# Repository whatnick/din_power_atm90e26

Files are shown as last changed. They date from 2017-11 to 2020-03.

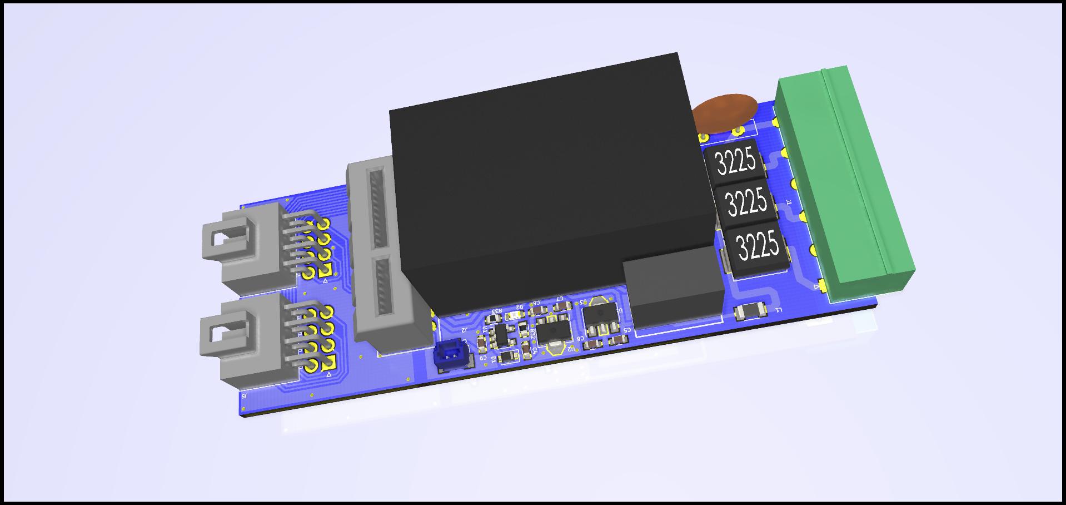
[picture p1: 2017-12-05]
din_power_atm90e26_front.jpg

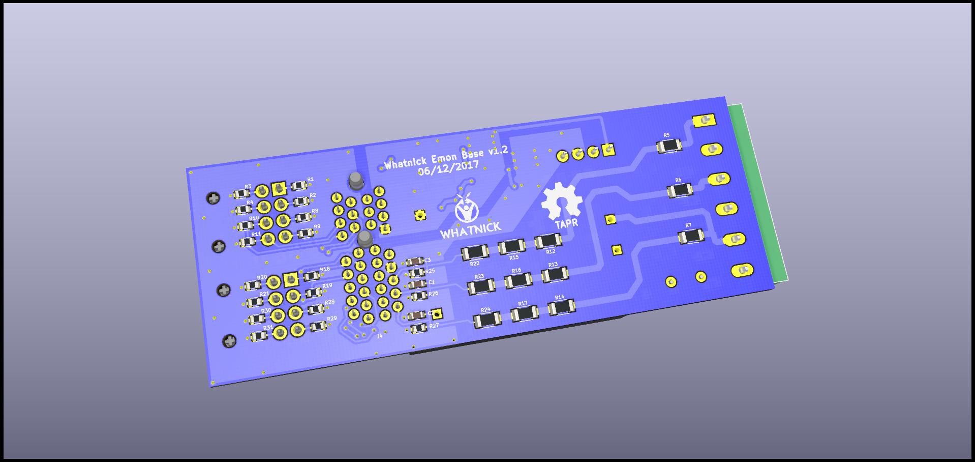
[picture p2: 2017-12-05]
din_power_atm90e26.jpg

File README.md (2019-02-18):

# DIN Rail Format Energy Meter Base Board
## Power SMPS module
- 90v-240v AC input
- Isolated 5V output
- 600mA / 3W power rating

## Over-voltage protection/over-current protection
- 0.1A rated PTC fuse
- 300V rated TVS suppressors, x1 per-phase

## Isolation
- 5v DC-DC isolator to power metering module

## Power supply clean-up
- x2 1117 series LDO for generating 3.3v from 5V input to clean up SMPS noise

## Backup-power
- MCP73831 series floating Lipo battery charger for backup lipo battery

## AC Voltage Sampler
- x3 Voltage divider ladders with 880K + 1K total serial resistance

## AC current Sampler
- x8 2.4ohm current sense resistor based CT clamp inputs

## Connectors
- 5.08mm spacing phoenix contact AC voltage connector
- Molex nanofit 2x4 type dense AC current clamp connectors

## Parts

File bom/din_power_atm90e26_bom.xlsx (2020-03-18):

References | manf# | Value | Footprint | Quantity
C4, C5, C6, C7, C8, C9 | 0603ZD105KAT2A | 1uF | C_0603 | 6
C1, C2, C3 | CC0603KRX7R9BB333 | 33n | C_0603 | 3
R5, R6, R7, R12, R13, R14, R15, R16, R17, R22, R23, R24 | CRCW1206220KFKEA | 220K | R_1206 | 12
R25, R26, R27, R33 | CRG0603F1K0 | 1K | R_0603 | 4
R1, R2, R3, R4, R8, R9, R10, R11, R18, R19, R20, R21, R28, R29, R30, R31 | CRL0603-FW-2R40ELF | 5.8R | R_0603 | 16
R32 | RT0603DRE072KL | 2K | R_0603 | 1
L1 | AIML-1206-R27K-T | Ferrite_Bead_Small | L_1206 | 1
D2 | LTST-C190KRKT | LED | LED_0603 | 1
D1 | PMEG1020EA | D_Schottky | D_SOD-323F | 1
U2, U3 | AP7365-33YG-13 | AP7365-33YG-13 | SOT-89-3 | 2
U4 | HLK-PM01 | Hi-Link_SMPS | HKLPM01 | 1
U1 | MCP73831T-3ACI/OT | MCP73831-2-OT | SOT-23-5 | 1
U5 | ROE-0505S | dc-dc | SIP4 | 1
F1 | 0ZRE0012FF1C | Polyfuse | C_Disc_D10.0mm_W2.5mm_P5.00mm | 1
RV1, RV2, RV3 | VP3225K401R275 | Varistor | SMD-4032 | 3
J4 | 10018784-10210TLF | CONN_02X18 | PCIE-36-SKT | 1
J3, J5 | 1053141108 | CONN_01X08 | Molex_NanoFit_2x04x2.50mm_Angled | 2
J1 | 1759059 | CONN_01X06 | PhoenixContact_MC-G_06x5.08mm_Angled | 1
J2 | BM02B-SRSS-TB(LFSN) | VBAT | JST_SH_BM02B-SRSS-TB_02x1.00mm_Straight | 1

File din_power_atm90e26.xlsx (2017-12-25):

Proj: | None |  |  |  |  |  | Board Qty: | 100
Co.: | None |  |  |  |  |  | Total Cost: | $0.00 |  |  |  | $0.00 |  |  |  |  | $0.00 |  |  |  |  | $0.00 |  |  |  |  | $0.00 |  |  |  |  | $0.00 |  |  |  |  | $0.00 |  |  |  |  | $0.00
Prj date: | None |  |  |  |  |  | Unit Cost: | $0.00 |  |  |  | 0 |  |  |  |  | 0 |  |  |  |  | 0 |  |  |  |  | 0 |  |  |  |  | 0 |  |  |  |  | 0 |  |  |  |  | 0
$ date: | 2017-12-25 13:13:31
Global Part Info |  |  |  |  |  |  |  |  | Digi-Key |  |  |  |  | Farnell |  |  |  |  | Mouser |  |  |  |  | Newark |  |  |  |  | Rs Components |  |  |  |  | Tme |  |  |  |  | Local
Refs | Value | Desc | Footprint | Manf | Manf# | Qty | Unit$ | Ext$ | Avail | Purch | Unit$ | Ext$ | Cat# | Avail | Purch | Unit$ | Ext$ | Cat# | Avail | Purch | Unit$ | Ext$ | Cat# | Avail | Purch | Unit$ | Ext$ | Cat# | Avail | Purch | Unit$ | Ext$ | Cat# | Avail | Purch | Unit$ | Ext$ | Cat# | Avail | Purch | Unit$ | Ext$ | Cat#
C1-C3 | 33n |  | Capacitors_SMD:C_0603 |  | CC0603KRX7R9BB333 | 0 | $0.00 | $0.00 | 132551 |  | $0.00 | $0.00 | 311-1429-1-ND (http://www.digikey.com/product-detail/en/yageo/CC0603KRX7R9BB333/311-1429-1-ND/2833735) |  |  |  |  |  |  |  |  |  |  | NonStk |  | $0.00 | $0.00 | 65R8273 (http://www.newark.com/webapp/wcs/stores/servlet/Search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) | 4 |  | $0.00 | $0.00 | 669-8836 (http://it.rs-online.com/web/c/?searchTerm=CC0603KRX7R9BB333+) | 33200 |  | $0.00 | $0.00 | CC0603KRX7R9333 (https://www.tme.eu/en/details/cc0603krx7r9333/0603-mlcc-smd-capacitors/yageo/cc0603krx7r9bb333/)
C4-C9 | 1uF |  | Capacitors_SMD:C_0603 |  | 0603ZD105KAT2A | 0 | $0.00 | $0.00 | 170608 |  | $0.00 | $0.00 | 478-1251-1-ND (http://www.digikey.com/product-detail/en/avx-corporation/0603ZD105KAT2A/478-1251-1-ND/564283) | 7506 |  | $0.00 | $0.00 | 1327684 (http://it.farnell.com/avx/0603zd105kat2a/condensatore-mlcc-x5r-1uf-10v/dp/1327684) |  |  |  |  |  | 19442 |  | $0.00 | $0.00 | 84K8388 (http://www.newark.com/avx/0603zd105kat2a/ceramic-capacitor-1uf-10v-x5r/dp/84K8388) |  |  |  |  |  | 10800 |  | $0.00 | $0.00 | 0603ZD105KAT2A (https://www.tme.eu/en/details/0603zd105kat2a/0603-mlcc-smd-capacitors/avx/)
D1 | D_Schottky |  | Diodes_SMD:D_SOD-323F |  | PMEG1020EA | 0 | $0.00 | $0.00 | NonStk |  | $0.00 | $0.00 | 1727-5185-1-ND (http://www.digikey.com/product-detail/en/nexperia-usa-inc/PMEG1020EA115/1727-5185-1-ND/2531784) | NonStk |  | $0.00 | $0.00 | 8737819 (http://it.farnell.com/nexperia/pmeg1020ea/diodo-schottky-sod-323/dp/8737819) |  |  |  |  |  | NonStk |  | $0.00 | $0.00 | 38K6864 (http://www.newark.com/nexperia/pmeg1020ea/schottky-rectifier-2a-10v-sc-76/dp/38K6864) | 1420 |  | $0.00 | $0.00 | 485-470 (http://it.rs-online.com/web/c/?searchTerm=PMEG1020EA+)
D2 | LED |  | LEDs:LED_0603 |  | LTST-C190KRKT | 0 | $0.00 | $0.00 | 1033408 |  | $0.00 | $0.00 | 160-1436-1-ND (http://www.digikey.com/product-detail/en/lite-on-inc/LTST-C190KRKT/160-1436-1-ND/386816) |  |  |  |  |  |  |  |  |  |  | 1991 |  | $0.00 | $0.00 | 09J9435 (http://www.newark.com/lumex/sml-lx0603siw-tr/led-red-0-8mm-x-1mm-60mcd-636nm/dp/09J9435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) | 100 |  | $0.00 | $0.00 | 692-0981 (http://it.rs-online.com/web/c/?searchTerm=LTST-C190KRKT+) | NonStk |  | $0.00 | $0.00 | LTST-C190KRKT (https://www.tme.eu/en/details/ltst-c190krkt/smd-colour-leds/liteon/)
F1 | Polyfuse |  | Capacitors_THT:C_Disc_D10.0mm_W2.5mm_P5.00mm |  | 0ZRE0012FF1C | 0 | $0.00 | $0.00 | 16473 |  | $0.00 | $0.00 | 507-1350-ND (http://www.digikey.com/scripts/DkSearch/dksus.dll?WT.z_header=search_go&lang=en)
J1 | CONN_01X06 |  | Connectors_Phoenix:PhoenixContact_MC-G_06x5.08mm_Angled |  | 1759059 | 0 | $0.00 | $0.00 | 775 |  | $0.00 | $0.00 | 277-1099-ND (http://www.digikey.com/scripts/DkSearch/dksus.dll?WT.z_header=search_go&lang=en&keywords=1759059+) | 43530 |  | $0.00 | $0.00 | 1759059 (http://it.farnell.com/multicomp/mc0603n330j500ct/condens-mlcc-c0g-np0-33pf-50v/dp/1759059) |  |  |  |  |  | NonStk |  |  |  | 14X6549 (http://www.newark.com/phoenix-contact/1759059/mstb-2-5-6-g-5-08/dp/14X6549)
J2 | VBAT |  | Connectors_JST:JST_SH_BM02B-SRSS-TB_02x1.00mm_Straight |  | BM02B-SRSS-TB(LFSN) | 0 | $0.00 | $0.00 | 24764 |  | $0.00 | $0.00 | 455-1788-1-ND (http://www.digikey.com/product-detail/en/jst-sales-america-inc/BM02B-SRSS-TB-LF-SN/455-1788-1-ND/926859) | 31065 |  | $0.00 | $0.00 | 1679127 (http://it.farnell.com/webapp/wcs/stores/servlet/Search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) |  |  |  |  |  | 5974 |  | $0.00 | $0.00 | 26P0950 (http://www.newark.com/webapp/wcs/stores/servlet/Search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)
J3,J5 | CONN_01X08 |  | Connectors_Molex:Molex_NanoFit_2x04x2.50mm_Angled |  | 1053141108 | 0 | $0.00 | $0.00 | 1652 |  | $0.00 | $0.00 | WM16909-ND (http://www.digikey.com/scripts/DkSearch/dksus.dll?WT.z_header=search_go&lang=en&keywords=1053141108+) | 131 |  | $0.00 | $0.00 | 2820690 (http://it.farnell.com/molex/105314-1108/connettore-bas-8pos-r-a-2file2/dp/2820690) |  |  |  |  |  | 1716 |  | $0.00 | $0.00 | 33AC7688 (http://www.newark.com/webapp/wcs/stores/servlet/Search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)
J4 | CONN_02X18 |  | hi-link_smps:PCIE-36-SKT |  | 10018784-10210TLF | 0 | $0.00 | $0.00 | 2100 |  | $0.00 | $0.00 | 609-2029-ND (http://www.digikey.com/scripts/DkSearch/dksus.dll?WT.z_header=search_go&lang=en)
L1 | Ferrite_Bead_Small |  | Inductors_SMD:L_1206 |  | AIML-1206-R27K-T | 0 | $0.00 | $0.00 | 29927 |  | $0.00 | $0.00 | 535-11684-1-ND (http://www.digikey.com/product-detail/en/abracon-llc/AIML-1206-R27K-T/535-11684-1-ND/2782899)
R1-R4,R8-R11,R18-R21,R28-R31 | 5.8R |  | Resistors_SMD:R_0603 |  | CPF0603B5R76E1 | 0 | $0.00 | $0.00 | NonStk |  | $0.00 | $0.00 | CPF0603B5R76E1-ND (http://www.digikey.com/scripts/DkSearch/dksus.dll?WT.z_header=search_go&lang=en) | 93 |  | $0.00 | $0.00 | 2331306 (http://it.farnell.com/te-connectivity/cpf0603b5r76e1/res-film-sott-5r76-0-1-0-063w/dp/2331306) |  |  |  |  |  | 1000 |  | $0.00 | $0.00 | 06AC1362 (http://www.newark.com/te-connectivity/cpf0603b5r76e1/res-thin-film-5r76-0-1-0-063w/dp/06AC1362)
R25-R27,R33 | 1K |  | Resistors_SMD:R_0603 |  | CRG0603F1K0 | 0 | $0.00 | $0.00 | 217123 |  | $0.00 | $0.00 | A106049CT-ND (http://www.digikey.com/product-detail/en/te-connectivity-passive-product/CRG0603F1K0/A106049CT-ND/3477689) |  |  |  |  |  |  |  |  |  |  | NonStk |  | $0.00 | $0.00 | 20R1193 (http://www.newark.com/te-connectivity-neohm/crg0603f1k0-10/crg0603-1-1k0-10k-rl/dp/20R1193)
R32 | 2K |  | Resistors_SMD:R_0603 |  | RT0603DRE072KL | 0 | $0.00 | $0.00 | 10769 |  | $0.00 | $0.00 | 311-2525-1-ND (http://www.digikey.com/product-detail/en/yageo/RT0603DRE072KL/311-2525-1-ND/6128944)
R5-R7,R12-R17,R22-R24 | 220K |  | Resistors_SMD:R_1206 |  | CRCW1206220KFKEA | 0 | $0.00 | $0.00 | 29958 |  | $0.00 | $0.00 | 541-220KFCT-ND (http://www.digikey.com/product-detail/en/vishay-dale/CRCW1206220KFKEA/541-220KFCT-ND/1182024) | 16072 |  | $0.00 | $0.00 | 2139620 (http://it.farnell.com/vishay/crcw1206220kfkea/res-film-spesso-220k-1-0-25w-1206/dp/2139620) |  |  |  |  |  | 6046 |  | $0.00 | $0.00 | 53K2157 (http://www.newark.com/vishay/crcw1206220kfkea/res-thick-film-220k-1-0-25w-1206/dp/53K2157) |  |  |  |  |  | NonStk |  | $0.00 | $0.00 | CRCW1206220KFKEA (https://www.tme.eu/en/details/crcw1206220kfkea/1206-smd-resistors/vishay/)
RV1-RV3 | Varistor |  | SMD_Packages:SMD-4032 |  | VP3225K401R275 | 0 | $0.00 | $0.00 | 2631 |  | $0.00 | $0.00 | 399-13808-1-ND (http://www.digikey.com/product-detail/en/kemet/VP3225K401R275/399-13808-1-ND/6362952) | 6035 |  | $0.00 | $0.00 | 2717784 (http://it.farnell.com/kemet/vp3225k401r275/varistore-mlv-710v-3225/dp/2717784) |  |  |  |  |  | 6035 |  | $0.00 | $0.00 | 14AC5483 (http://www.newark.com/webapp/wcs/stores/servlet/Search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)
U1 | MCP73831-2-OT |  | TO_SOT_Packages_SMD:SOT-23-5 |  | MCP73831T-3ACI/OT | 0 | $0.00 | $0.00 | NonStk |  | $0.00 | $0.00 | MCP73831T-3ACI/OTTR-ND (http://www.digikey.com/product-detail/en/microchip-technology/MCP73831T-3ACI-OT/MCP73831T-3ACI-OTTR-ND/964307) |  |  |  |  |  |  |  |  |  |  | NonStk |  | $0.00 | $0.00 | 56K7051 (http://www.newark.com/webapp/wcs/stores/servlet/Search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)
U2,U3 | AP7365-33YG-13 |  | TO_SOT_Packages_SMD:SOT-89-3 |  | AP7365-33YG-13 | 0 | $0.00 | $0.00 | NonStk |  | $0.00 | $0.00 | AP7365-33YG-13DI-ND (http://www.digikey.com/scripts/DkSearch/dksus.dll?WT.z_header=search_go&lang=en)
U4 | Hi-Link_SMPS |  | hi-link_smps:HKLPM01 |  |  | 0 | $0.00 | $0.00 |  |  |  |  |  |  |  |  |  |  |  |  |  |  |  |  |  |  |  |  |  |  |  |  |  |  |  |  |  |  | NonStk |  | $0.00 | $0.00 | #AB80C0DC401ACD3
U5 | dc-dc |  | hi-link_smps:SIP4 |  | ROE-0505S | 0 | $0.00 | $0.00 | 12646 |  | $0.00 | $0.00 | 945-1655-5-ND (http://www.digikey.com/scripts/DkSearch/dksus.dll?WT.z_header=search_go&lang=en&keywords=ROE-0505S+) | 7726 |  | $0.00 | $0.00 | 2218597 (http://it.farnell.com/webapp/wcs/stores/servlet/Search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) |  |  |  |  |  | 198 |  | $0.00 | $0.00 | 63X9545 (http://www.newark.com/webapp/wcs/stores/servlet/Search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) | 42 |  | $0.00 | $0.00 | 777-3285 (http://it.rs-online.com/web/c/?searchTerm=ROE-0505S+)
 |  |  |  |  |  |  |  |  |  | 0 |  |  |  |  | 0 |  |  |  |  | 0 |  |  |  |  | 0 |  |  |  |  | 0 |  |  |  |  | 0 |  |  |  |  | 0
 |  |  |  |  |  |  |  |  |  | 0 | 0 | 0 |  |  | 0 | 0 | 0 |  |  | 0 | 0 | 0 |  |  | 0 | 0 | 0 |  |  | 0 | 0 | 0 |  |  | 0 | 0 | 0 |  |  | 0 | 0 | 0
 |  |  |  |  |  |  |  |  |  | 0 | 0 | 0 |  |  | 0 | 0 | 0 |  |  | 0 | 0 | 0 |  |  | 0 | 0 | 0 |  |  | 0 | 0 | 0 |  |  | 0 | 0 | 0 |  |  | 0 | 0 | 0
 |  |  |  |  |  |  |  |  |  | 0 | 0 | 0 |  |  | 0 | 0 | 0 |  |  | 0 | 0 | 0 |  |  | 0 | 0 | 0 |  |  | 0 | 0 | 0 |  |  | 0 | 0 | 0 |  |  | 0 | 0 | 0
 |  |  |  |  |  |  |  |  |  | 0 | 0 | 0 |  |  | 0 | 0 | 0 |  |  | 0 | 0 | 0 |  |  | 0 | 0 | 0 |  |  | 0 | 0 | 0 |  |  | 0 | 0 | 0 |  |  | 0 | 0 | 0
 |  |  |  |  |  |  |  |  |  | 0 | 0 | 0 |  |  | 0 | 0 | 0 |  |  | 0 | 0 | 0 |  |  | 0 | 0 | 0 |  |  | 0 | 0 | 0 |  |  | 0 | 0 | 0 |  |  | 0 | 0 | 0
 |  |  |  |  |  |  |  |  |  | 0 | 0 | 0 |  |  | 0 | 0 | 0 |  |  | 0 | 0 | 0 |  |  | 0 | 0 | 0 |  |  | 0 | 0 | 0 |  |  | 0 | 0 | 0 |  |  | 0 | 0 | 0
 |  |  |  |  |  |  |  |  |  | 0 | 0 | 0 |  |  | 0 | 0 | 0 |  |  | 0 | 0 | 0 |  |  | 0 | 0 | 0 |  |  | 0 | 0 | 0 |  |  | 0 | 0 | 0 |  |  | 0 | 0 | 0
 |  |  |  |  |  |  |  |  |  | 0 | 0 | 0 |  |  | 0 | 0 | 0 |  |  | 0 | 0 | 0 |  |  | 0 | 0 | 0 |  |  | 0 | 0 | 0 |  |  | 0 | 0 | 0 |  |  | 0 | 0 | 0
 |  |  |  |  |  |  |  |  |  | 0 | 0 | 0 |  |  | 0 | 0 | 0 |  |  | 0 | 0 | 0 |  |  | 0 | 0 | 0 |  |  | 0 | 0 | 0 |  |  | 0 | 0 | 0 |  |  | 0 | 0 | 0
 |  |  |  |  |  |  |  |  |  | 0 | 0 | 0 |  |  | 0 | 0 | 0 |  |  | 0 | 0 | 0 |  |  | 0 | 0 | 0 |  |  | 0 | 0 | 0 |  |  | 0 | 0 | 0 |  |  | 0 | 0 | 0
 |  |  |  |  |  |  |  |  |  | 0 | 0 | 0 |  |  | 0 | 0 | 0 |  |  | 0 | 0 | 0 |  |  | 0 | 0 | 0 |  |  | 0 | 0 | 0 |  |  | 0 | 0 | 0 |  |  | 0 | 0 | 0
 |  |  |  |  |  |  |  |  |  | 0 | 0 | 0 |  |  | 0 | 0 | 0 |  |  | 0 | 0 | 0 |  |  | 0 | 0 | 0 |  |  | 0 | 0 | 0 |  |  | 0 | 0 | 0 |  |  | 0 | 0 | 0
 |  |  |  |  |  |  |  |  |  | 0 | 0 | 0 |  |  | 0 | 0 | 0 |  |  | 0 | 0 | 0 |  |  | 0 | 0 | 0 |  |  | 0 | 0 | 0 |  |  | 0 | 0 | 0 |  |  | 0 | 0 | 0
 |  |  |  |  |  |  |  |  |  | 0 | 0 | 0 |  |  | 0 | 0 | 0 |  |  | 0 | 0 | 0 |  |  | 0 | 0 | 0 |  |  | 0 | 0 | 0 |  |  | 0 | 0 | 0 |  |  | 0 | 0 | 0
 |  |  |  |  |  |  |  |  |  | 0 | 0 | 0 |  |  | 0 | 0 | 0 |  |  | 0 | 0 | 0 |  |  | 0 | 0 | 0 |  |  | 0 | 0 | 0 |  |  | 0 | 0 | 0 |  |  | 0 | 0 | 0
 |  |  |  |  |  |  |  |  |  | 0 | 0 | 0 |  |  | 0 | 0 | 0 |  |  | 0 | 0 | 0 |  |  | 0 | 0 | 0 |  |  | 0 | 0 | 0 |  |  | 0 | 0 | 0 |  |  | 0 | 0 | 0
 |  |  |  |  |  |  |  |  |  | 0 | 0 | 0 |  |  | 0 | 0 | 0 |  |  | 0 | 0 | 0 |  |  | 0 | 0 | 0 |  |  | 0 | 0 | 0 |  |  | 0 | 0 | 0 |  |  | 0 | 0 | 0
 |  |  |  |  |  |  |  |  |  | 0 | 0 | 0 |  |  | 0 | 0 | 0 |  |  | 0 | 0 | 0 |  |  | 0 | 0 | 0 |  |  | 0 | 0 | 0 |  |  | 0 | 0 | 0 |  |  | 0 | 0 | 0
 |  |  |  |  |  |  |  |  |  | 0 | 0 | 0 |  |  | 0 | 0 | 0 |  |  | 0 | 0 | 0 |  |  | 0 | 0 | 0 |  |  | 0 | 0 | 0 |  |  | 0 | 0 | 0 |  |  | 0 | 0 | 0

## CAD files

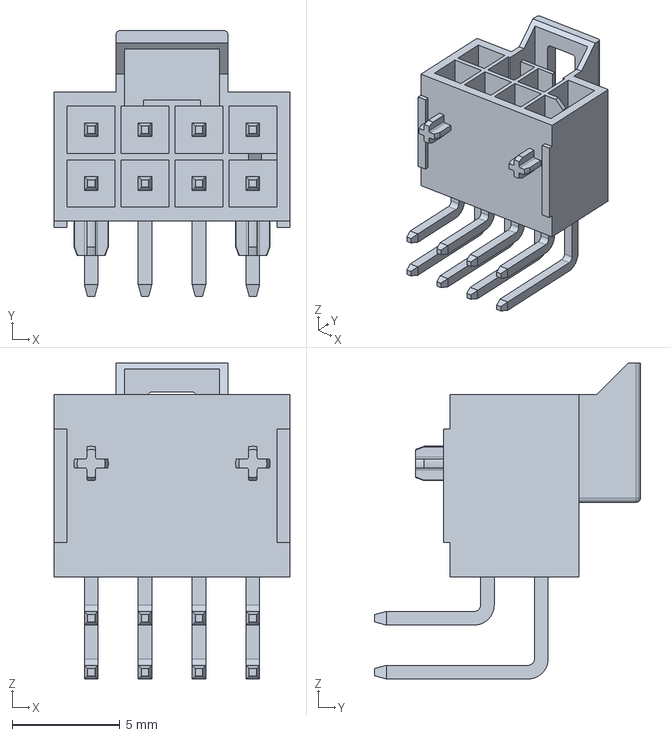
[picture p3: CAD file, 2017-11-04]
3dmodels/1053141208.stp
10.9 x 12.3 x 14.7 mm

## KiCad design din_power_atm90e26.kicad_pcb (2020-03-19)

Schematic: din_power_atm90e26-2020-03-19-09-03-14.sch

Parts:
C1, C2, C3: 33n; C_0603
C4, C5, C6, C7, C8, C9: 1uF; C_0603
D1: D_Schottky; D_SOD-323F
D2: LED; LED_0603
F1: Polyfuse; C_Disc_D10.0mm_W2.5mm_P5.00mm
G1: LOGO; Whatnick_logo
J1: CONN_01X06; PhoenixContact_MC-G_06x5.08mm_Angled
J2: VBAT; JST_SH_BM02B-SRSS-TB_02x1.00mm_Straight
J3, J5: CONN_01X08; Molex_NanoFit_2x04x2.50mm_Angled
J4: CONN_02X18; PCIE-36-SKT
L1: Ferrite_Bead_Small; L_1206
LOGO_OSHW1: Logo_Open_Hardware_Small; OSHW-Symbol_6.7x6mm_SilkScreen
R1, R2, R3, R4, R8, R9, R10, R11, R18, R19, R20, R21, R28, R29, R30, R31: 5.8R; R_0603
R5, R6, R7, R12, R13, R14, R15, R16, R17, R22, R23, R24: 220K; R_1206
R25, R26, R27, R33: 1K; R_0603
R32: 2K; R_0603
RV1, RV2, RV3: Varistor; SMD-4032
SYM1: SYM_Flash_Small; Fsilk_HV
U1: MCP73831-2-OT; SOT-23-5
U2, U3: AP7365-33YG-13; SOT-89-3
U4: Hi-Link_SMPS; HKLPM01
U5: dc-dc; SIP4

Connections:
+3.3V_ISO: C8.1, J4.8, U3.1 (VO)
+3V3: C7.1, J4.32, U2.1 (VO)
+5V_ISO: C5.1, J4.9, U3.3 (VI), U5.4
/UN_IN: F1.1, U4.2 (AC_N)
/ua_1: R5.1, R12.2
/ua_2: R12.1, R15.2
/ua_3: R15.1, R22.2
/ub_1: R6.1, R13.2
/ub_2: R13.1, R16.2
/ub_3: R16.1, R23.2
/uc_1: R7.1, R14.2
/uc_2: R14.1, R17.2
/uc_3: R17.1, R24.2
GNDA: C1.2, C2.2, C3.2, C5.2, C8.2, J4.7, L1.1, R1.1, R2.2, R3.1, R4.2, R8.1, R9.2, R10.1, R11.2, R18.1, R19.2, R20.1, R21.2, R25.1, R26.1, R27.1, R28.1, R29.2, R30.1, R31.2, U3.2 (GND), U5.3
GNDPWR: C4.2, C6.2, C7.2, C9.1, J2.2, J4.36, R32.2, U1.2 (Vss), U2.2 (GND), U4.3 (-VO), U5.1
IA1+: J4.11, J5.1, R1.2
IA1-: J4.13, J5.2, R2.1
IA2+: J3.1, J4.27, R18.2
IA2-: J3.2, J4.29, R19.1
IB1+: J4.15, J5.3, R8.2
IB1-: J4.17, J5.4, R9.1
IB2+: J3.3, J4.31, R28.2
IB2-: J3.4, J4.33, R29.1
IC1+: J4.19, J5.5, R3.2
IC1-: J4.21, J5.6, R4.1
IC2+: J3.5, J4.35, R20.2
IC2-: J3.6, J4.2, R21.1
IN1+: J4.23, J5.7, R10.2
IN1-: J4.25, J5.8, R11.1
IN2+: J3.7, J4.4, R30.2
IN2-: J3.8, J4.6, R31.1
unnamed: D2.1, R33.1
unnamed: R32.1, U1.5 (PROG)
unnamed: R33.2, U1.1 (STAT)
UA: J1.1, R5.2, RV1.2
UA_SAMP: C3.1, J4.5, R22.1, R25.2
UB: J1.3, R6.2, RV2.2
UB_SAMP: C1.1, J4.3, R23.1, R26.2
UC: J1.5, R7.2, RV3.2, U4.1 (AC_L)
UC_SAMP: C2.1, J4.1, R24.1, R27.2
UN: F1.2, J1.6, L1.2, RV1.1, RV2.1, RV3.1
VBAT: C9.2, D1.2, J2.1, J4.30, U1.3 (Vbat)

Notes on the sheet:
Power Systems (5V)
Voltage Sampling
Current Sampling
CT Input
Connector for Metering/Processor boards - Supplies IV samples and +5V power with/without isolation
Optional N-CT1
Option N-CT2
Power Systems - Battery and 3.3V

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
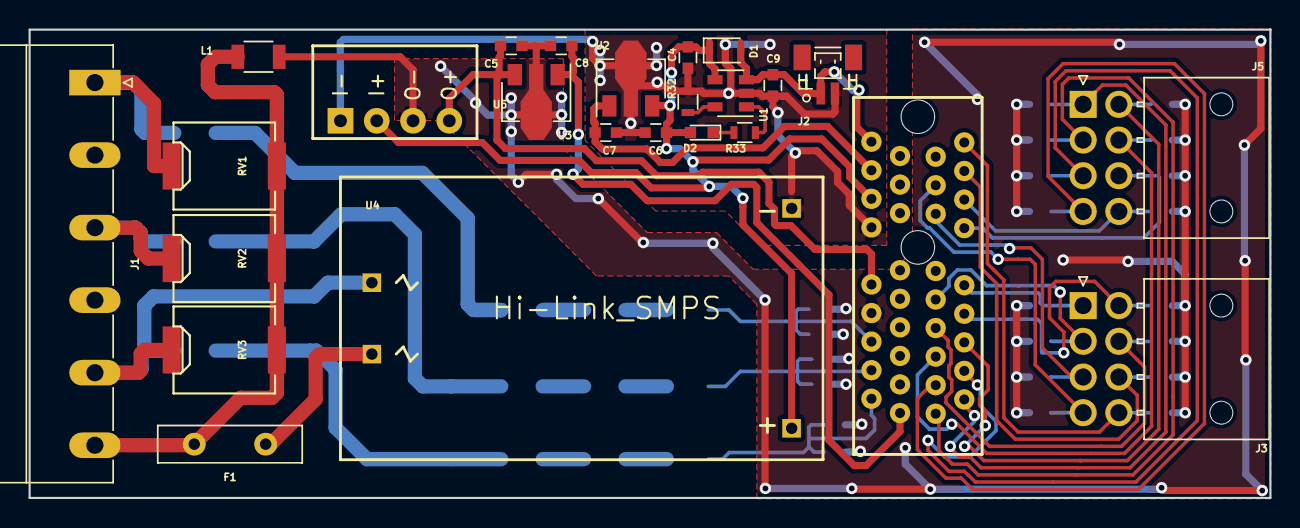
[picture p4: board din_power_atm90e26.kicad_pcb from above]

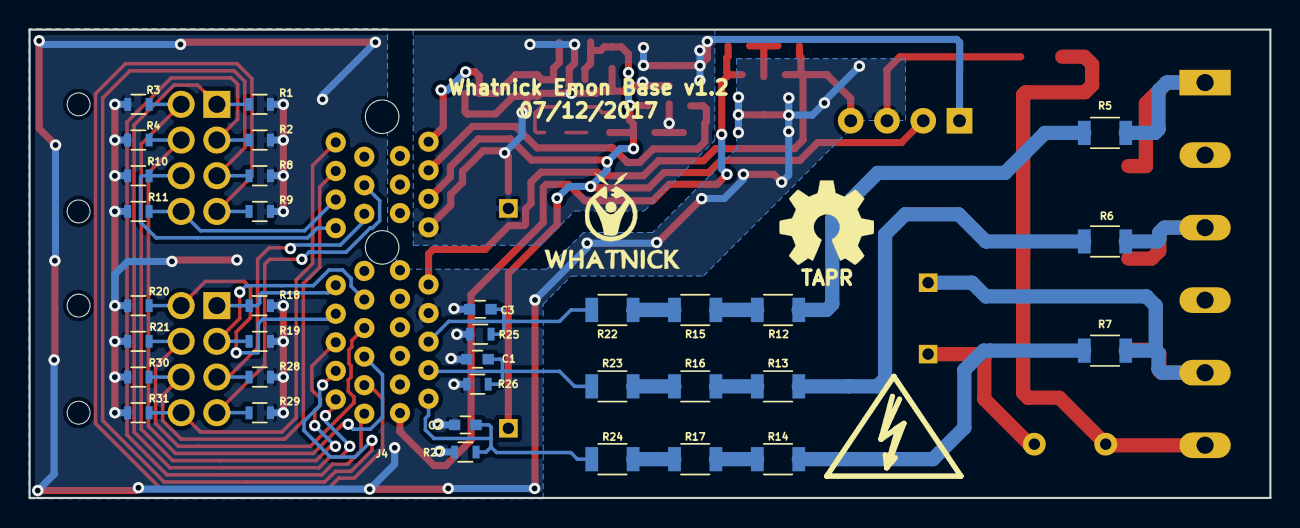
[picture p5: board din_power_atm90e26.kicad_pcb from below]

Board: 2 copper layers, 86.9 x 32.8 mm, 62 parts (38 on the bottom side), 43 nets.

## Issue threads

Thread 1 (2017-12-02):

Correct pins for LDO

whatnick, 2017-12-02:
Pins for LDO are assigned from KiCAD library to correspond to TLV1117 SOT-223 package. This does not match the chosen part: http://www.mouser.com/ds/2/115/AP7365-86154.pdf , schematic and footprint have to be corrected.

Closed 2017-12-08.

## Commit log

2017-11-04 Initial import laying out parts
    [1053141208.stp, din_power_atm90e26.kicad_pcb, din_power_atm90e26.sch]
2017-11-04 Layout footprints
    [din_power_atm90e26.kicad_pcb]
2017-11-12 Changes from urbito
    [din_power_atm90e26.kicad_pcb]
2017-11-12 DRC change
    [din_power_atm90e26.kicad_pcb]
2017-11-13 Second iteration
    [din_power_atm90e26.kicad_pcb]
2017-11-16 Urbito work 16/11/2017
    [din_power_atm90e26.kicad_pcb]
2017-11-17 Urbito work 17/11/2017
    [din_power_atm90e26.kicad_pcb]
2017-11-18 Urbito delivery 18/11/2017
    [din_power_atm90e26.kicad_pcb]
2017-11-18 Reroute sections, clean up silk screen
    [din_power_atm90e26.kicad_pcb]
2017-11-18 Add OSHW logo
    [din_power_atm90e26.kicad_pcb, din_power_atm90e26.sch]
2017-11-22 Generate gerbers
    [din_power_atm90e26-B.Cu.gbl, din_power_atm90e26-B.Mask.gbs, din_power_atm90e26-B.Paste.gbp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]
2017-11-22 Add dimensions
    [din_power_atm90e26.kicad_pcb]
2017-11-27 Add more part numbers
    [din_power_atm90e26.sch]
2017-12-02 Address issue #1 with changes to schematic component
    [din_power_atm90e26.kicad_pcb, din_power_atm90e26.sch]
2017-12-05 New routing from Joslyn address #1
    [din_power_atm90e26.kicad_pcb, din_power_atm90e26.xlsx]
2017-12-05 Moved some parts and bumped version
    [din_power_atm90e26.kicad_pcb]
2017-12-05 Changed 3D models
    [din_power_atm90e26.kicad_pcb]
2017-12-05 Add new part numbers and high voltage sym
    [din_power_atm90e26.kicad_pcb, din_power_atm90e26.sch]
2017-12-07 Small silk screen changes and bump date
    [din_power_atm90e26.kicad_pcb]
2017-12-07 New gerbers
    [din_power_atm90e26-B.Cu.gbl, din_power_atm90e26-B.Mask.gbs, din_power_atm90e26-B.Paste.gbp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]
2017-12-25 Update parts to fit Kicost
    [din_power_atm90e26.kicad_pcb, din_power_atm90e26.sch, din_power_atm90e26.xlsx]
2018-02-24 Added MSTBA phoenix contact 3D model
    [din_power_atm90e26.kicad_pcb]
2019-02-18 Updated CAD output
2019-04-16 Remap 3D models
    [din_power_atm90e26.kicad_pcb]
2020-03-18 Port to KiCAD v5.0
    [din_power_atm90e26-2020-03-19-09-03-14.sch, din_power_atm90e26.kicad_pcb]
2020-03-18 New gerbers and gitignore
    [din_power_atm90e26-B.Cu.gbl, din_power_atm90e26-B_Cu.gbl, din_power_atm90e26-B_Mask.gbs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]
2020-03-18 Move BOM and dimension PCB
    [din_power_atm90e26.kicad_pcb, din_power_atm90e26_bom.xlsx]
2020-03-18 New location for BOM
    [din_power_atm90e26_bom.xlsx]
2020-03-19 Generate new gerbers
    [din_power_atm90e26-B_Cu.gbl, din_power_atm90e26-B_Mask.gbs, din_power_atm90e26-B_Paste.gbp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]
